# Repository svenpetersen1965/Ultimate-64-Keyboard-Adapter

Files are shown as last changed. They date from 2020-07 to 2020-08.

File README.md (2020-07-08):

# Ultimate-64-Keyboard-Adapter
This is an extension for the Ultimate 64 (elite) keyboard connector to get it into a position, that can be reached easily with the standard length keyboard cable. 

The project includes a 3D printed 16mm stand off, that fits the mounting hole. It fits with this 3D printed <a href="https://www.thingiverse.com/thing:3220123">mounting bracket</a> that can be found on thingiverse.com.

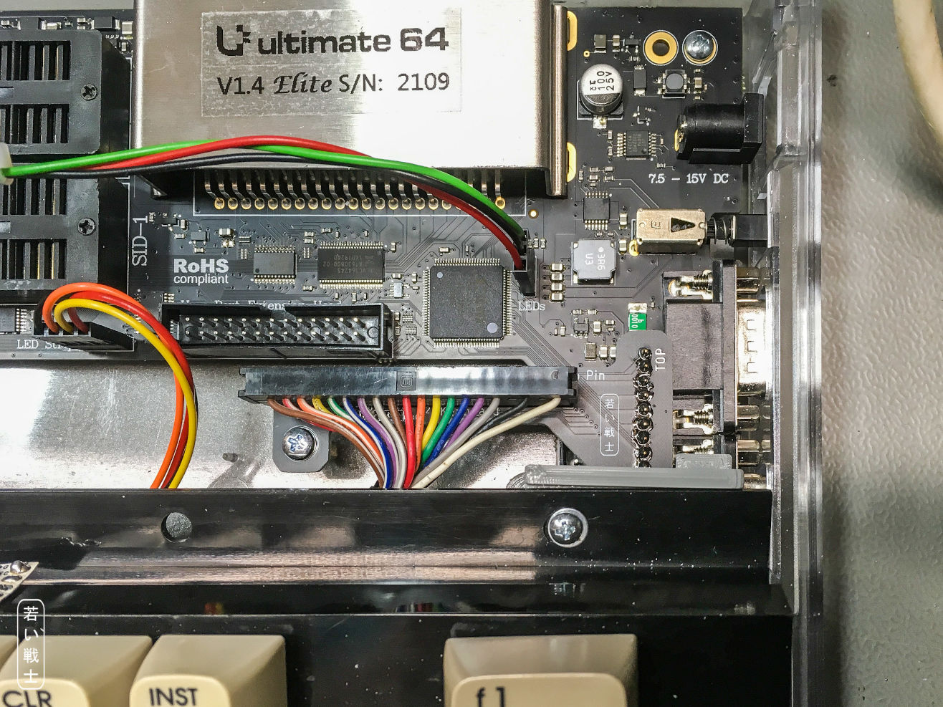
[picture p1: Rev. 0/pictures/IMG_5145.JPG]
U64 KB Adapter mounted


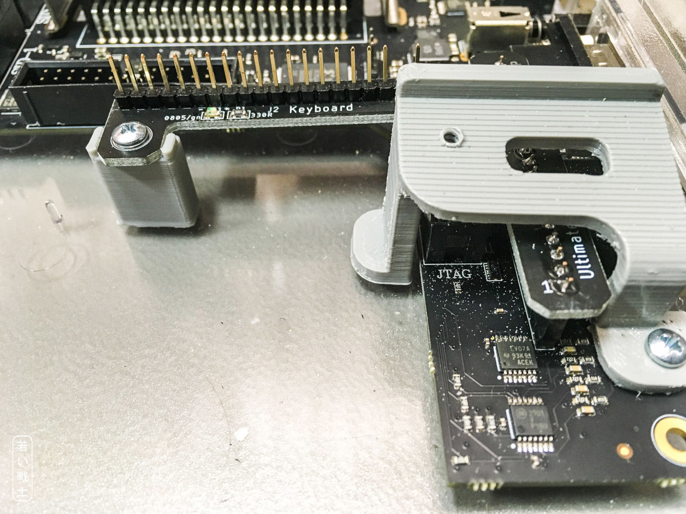
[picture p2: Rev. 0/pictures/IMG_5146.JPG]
U64 KB Adapterwith standoff


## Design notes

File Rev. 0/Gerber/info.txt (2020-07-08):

      
       Board: U64_KB_Ada
       Rev.:  0
  
       Files:
       ======
  
       All Gerber files are generated in extended gerber format (RS274X)
       *.TOP        : Film top copper
       *.BOT        :  -"- bottom copper
       *.STC        :  -"- top soldermask 
       *.STS        :  -"- bottom soldermask
       *.PLC        :  -"- silk screen top
       *.PLS        :  -"- silk screen bottom
       *.CRC        :  -"- cream top
       *.DK         : Drills plated Through (Excellon)
       *.NDK        : Drills not plated Through (Excellon)
       *.OUT        : Board outline

       Board Size:
       ===========
       Length     :   71.0 mm
       Width      :   56.0 mm
       Thickness  :   1.6 mm
       Material   :   FR 4
       Copper     :   35 um
       Surface    :   HASL
       
       Remarks:
       ========
       minimum drill: 0.35mm
       minimum width: 6 mil
       minimum distance: 6 mil

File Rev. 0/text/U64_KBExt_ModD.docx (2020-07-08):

Ultimate 64 Keyboard Extension Rev. 0

Module Description

This is a keyboard extension for the Ultimate 64. It was designed in collaboration with @edu_arana.

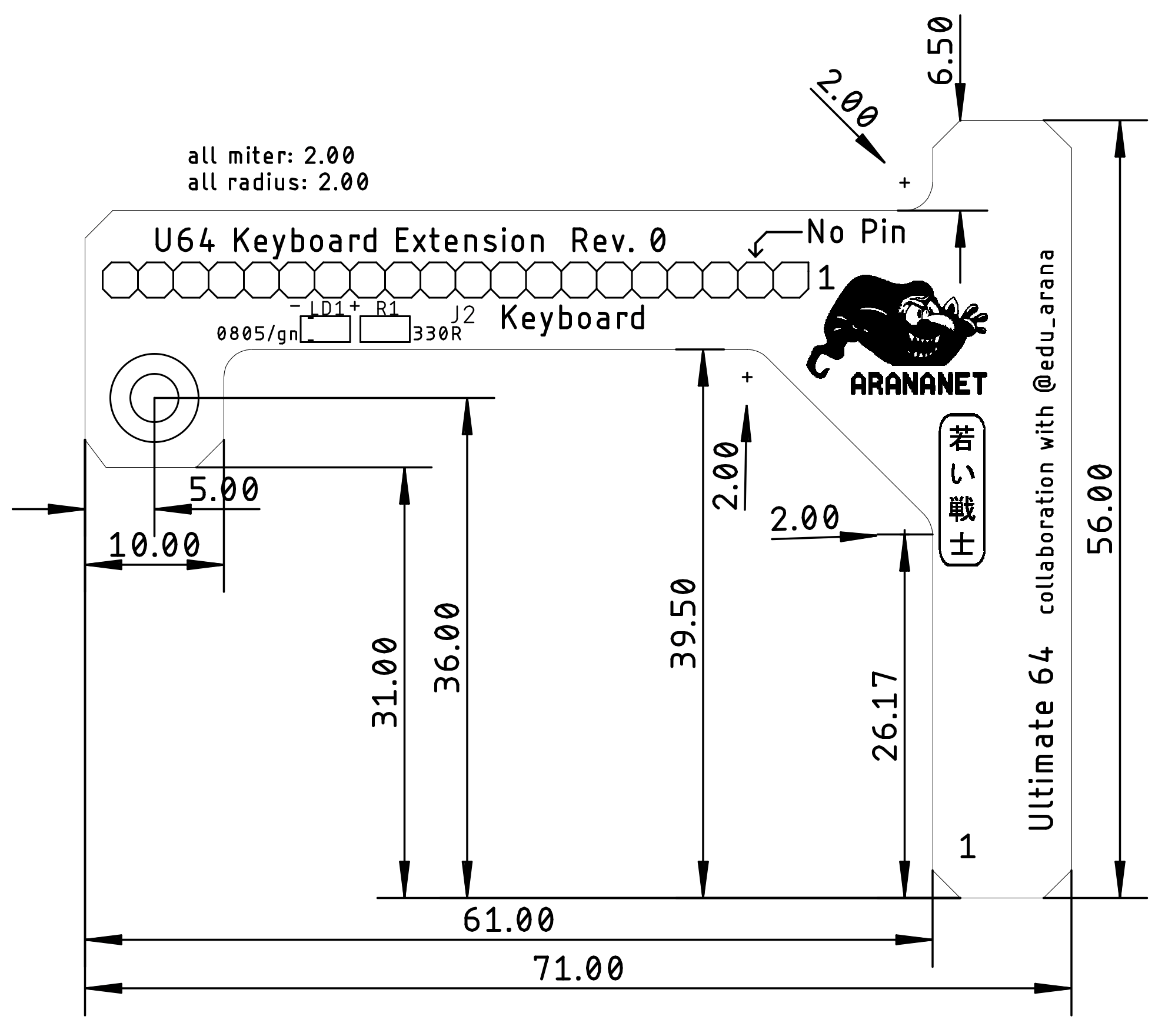
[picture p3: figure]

Figure 1: Dimensions

When using the 3D printed keyboard mounting bracket (https://www.thingiverse.com/thing:3220123), the access to the keyboard connector is blocked. Also, some keyboard cables are too short, so it does not reach the position of the connector or it is installed with a not acceptable tension. The Ultimate 64 Keyboard Extension fixes this problem.

The PCB offers an optional power LED (SMD 0805).

# Connectors

## J1 - Keyboard connector to Ultimate 64

Receptacle (1x20p, pitch 2.54mm) – Harwin M20-7862042

Pin | Signal | Pin | Signal
1 | GND | 11 | ROW1 (PB1)
2 | No pin | 12 | ROW0 (PB0)
3 | | 13 | COL0 (PA0)
4 | +5V | 14 | COL6 (PA6)
5 | ROW3 (PB3) | 15 | COL5 (PA5)
6 | ROW6 (PB6) | 16 | COL4 (PA4)
7 | ROW5 (PB5) | 17 | COL3 (PA3)
8 | ROW4 (PB4) | 18 | COL2 (PA2)
9 | ROW7 (PB7) | 19 | COL1 (PA1)
10 | ROW2 (PB2) | 20 | COL7 (PA7)

## J2 – Pin Header to Keyboard

Standard 1x20p, pitch 2.54. Pin 2 has to be removed to fit the C64 keyboard connector. The pin out is identical to J1.

# Mounting

The distance between this keyboard extension and the bottom of the case depends on the height of the receptacle. With a 8mm high receptacle, it is approximately 16mm. The project includes 3D printed a stand-off of this height.


Figure 2: Mounting of the keyboard extension with stand-off and keyboard bracket

The recommended screw for the stand-off is a C2.9x9.5 DIN 7981.


Figure 3: Complete assembly with keyboard installed

U64_KBExt_ModD.docx 26.06.2020 09:07 Drafted by Sven Petersen Page 2 of 2 Doc.-No.: 151-6-01-00

U64_KBExt_ModD.docx 26.06.2020 09:07 Drafted by Sven Petersen Page 1 of 1 Doc.-No.: 151-6-01-00

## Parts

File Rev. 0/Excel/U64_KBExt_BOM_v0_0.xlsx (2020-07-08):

Ultimate 64 Keyboard Extension Rev. 0
Bill of Material Rev. 0.0
Pos. | Qty | Value | Footprint | Ref.-No. | Comment
1 | 1 | 151-2-01-00 | 2 Layer | PCB Rev. 0 | 2 layer, Cu 35µ, HASL, LLL x BBB, 1.6mm FR4
2 | 1 | 1x20, 2.54mm, h=8mm | 1x20 | J1 | standard receptacle for pin header, pitch 2.54mm, height appr. 8mm
3 | 1 | 1x20p, 2.54mm | 1x20p | J2 | standard pin header 1x20p, pitch 2.54, pin 2 removed
4 | 1 | 330R | 0805 | R1 | optional, SMD 0805 resistor 10% or better
5 | 1 | LED 0805/green | LED0805 | LD1 | optional SMD LED

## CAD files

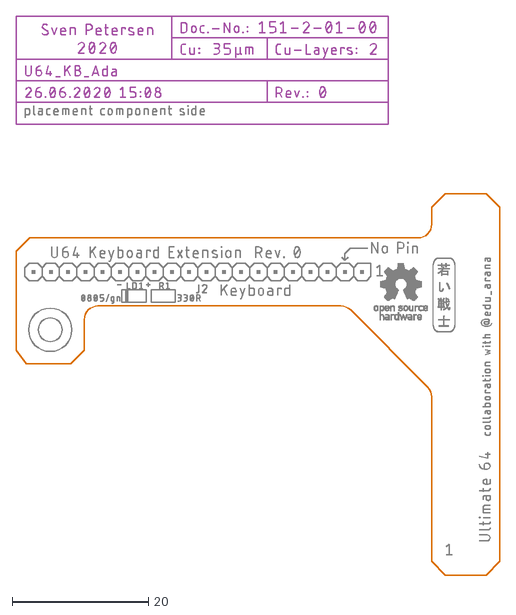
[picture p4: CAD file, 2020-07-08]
Rev. 0/dxf/U64_KB_Ada.dxf
71.0 x 82.1

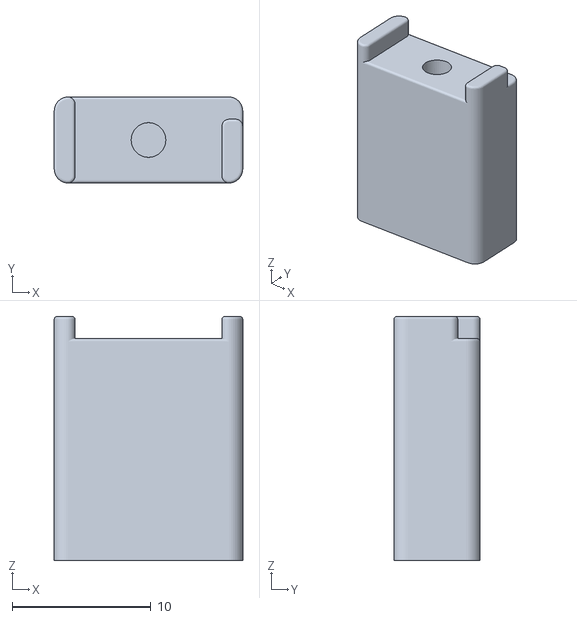
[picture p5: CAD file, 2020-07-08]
Stand_off/STL/U64_KeybExt_StandOff.stl
13.6 x 6.20 x 17.6

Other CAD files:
Stand_off/Fusion360/U64_KeybExt_Support v2.f3d

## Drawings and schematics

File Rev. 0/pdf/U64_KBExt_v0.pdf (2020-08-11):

# Project Documentation

## Ultimate 64 Keyboard Extension

## Project number: 151

## Revision: 0

## Date: 26.06.2020


U64_KBExt_ModD.docx | | 26.06.2020 09:07
Drafted by Sven Petersen | Page 1 of 3 | Doc.-No.: 151-6-01-00

### Ultimate 64 Keyboard Extension Rev. 0

### Module Description

This is a keyboard extension for the Ultimate 64. It was designed in collaboration with @edu_arana.

Figure 1: Dimensions

When using the 3D printed keyboard mounting bracket (https://www.thingiverse.com/thing:3220123), the access to the keyboard connector is blocked. Also, some keyboard cables are too short, so it does not reach the position of the connector or it is installed with a not acceptable tension. The Ultimate 64 Keyboard Extension fixes this problem.

The PCB offers an optional power LED (SMD 0805).

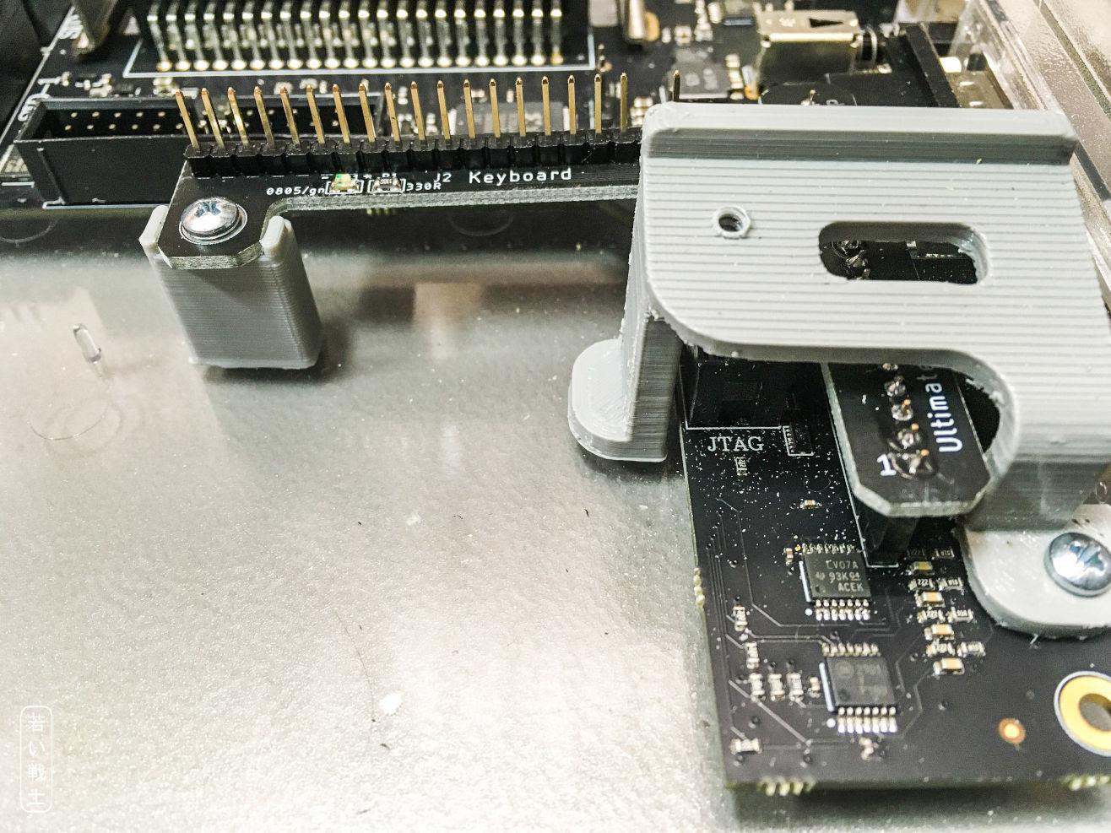
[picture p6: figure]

U64_KBExt_ModD.docx | | 26.06.2020 09:07
Drafted by Sven Petersen | Page 2 of 3 | Doc.-No.: 151-6-01-00

## Connectors

### J1 - Keyboard connector to Ultimate 64

Receptacle (1x20p, pitch 2.54mm) – Harwin M20-7862042

Pin Signal | Pin Signal
1 | GND | 11 | ROW1 (PB1)
2 | No pin | 12 | ROW0 (PB0)
3 RESTORE | | 13 COL0 (PA0)
4 | +5V | 14 | COL6 (PA6)
5 | ROW3 (PB3) | 15 | COL5 (PA5)
6 | ROW6 (PB6) | 16 | COL4 (PA4)
7 | ROW5 (PB5) | 17 | COL3 (PA3)
8 | ROW4 (PB4) | 18 | COL2 (PA2)
9 | ROW7 (PB7) | 19 | COL1 (PA1)
10 | ROW2 (PB2) | 20 | COL7 (PA7)

### J2 – Pin Header to Keyboard

Standard 1x20p, pitch 2.54. Pin 2 has to be removed to fit the C64 keyboard connector. The pin out is identical to J1.

## Mounting

The distance between this keyboard extension and the bottom of the case depends on the height of the receptacle. With a 8mm high receptacle, it is approximately 16mm. The project includes 3D printed a stand-off of this height.

Figure 2: Mounting of the keyboard extension with stand-off and keyboard bracket

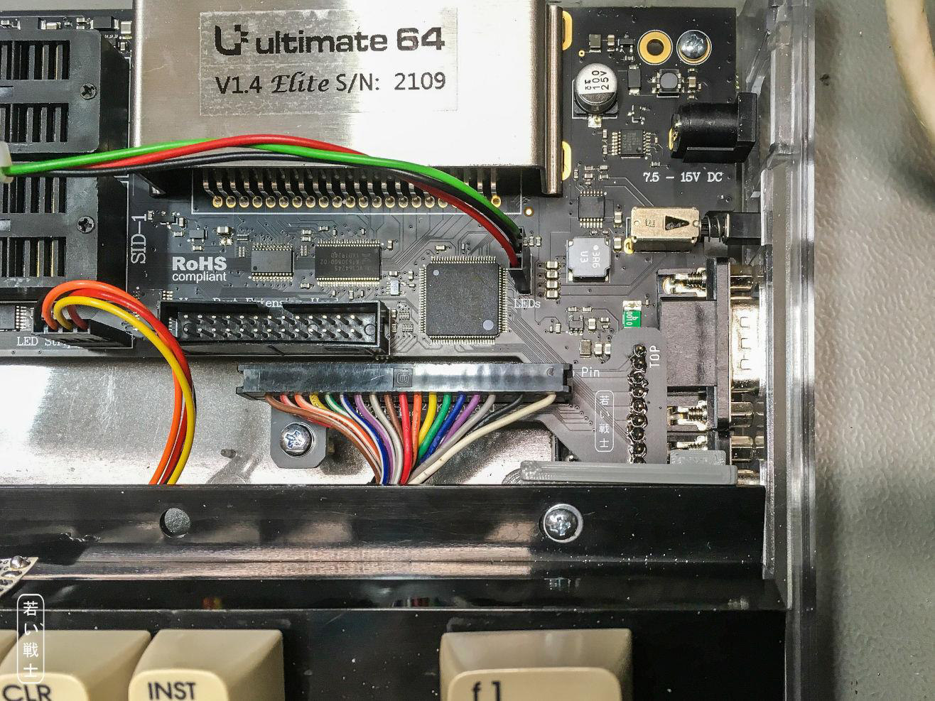
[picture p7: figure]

U64_KBExt_ModD.docx | | 26.06.2020 09:07
Drafted by Sven Petersen | Page 3 of 3 | Doc.-No.: 151-6-01-00

The recommended screw for the stand-off is a C2.9x9.5 DIN 7981.

Figure 3: Complete assembly with keyboard installed

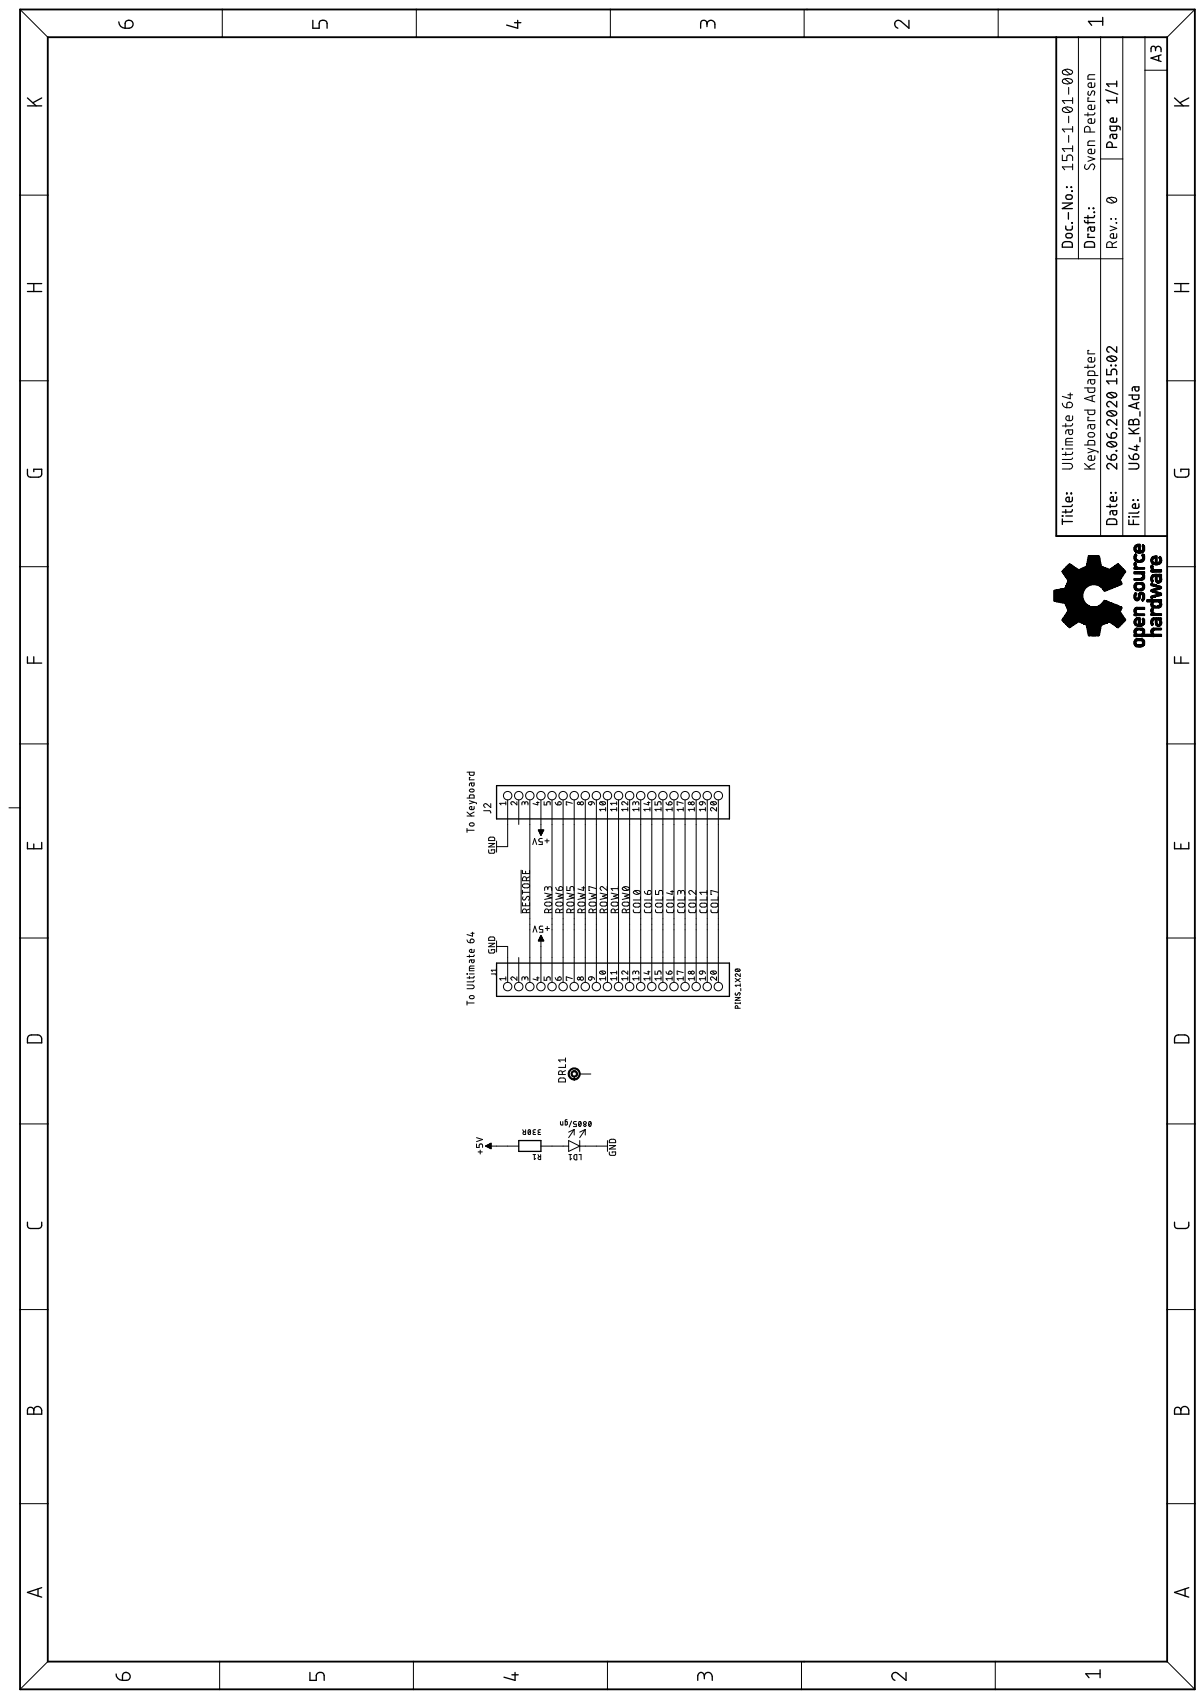
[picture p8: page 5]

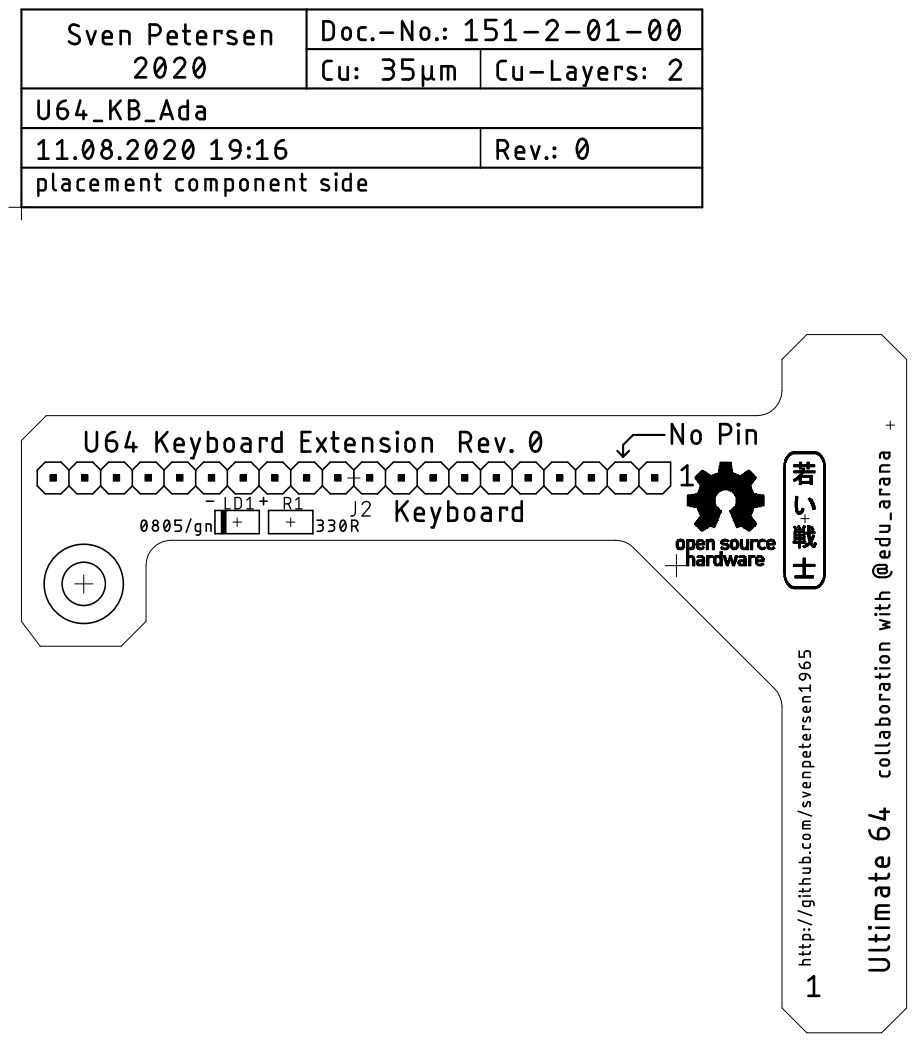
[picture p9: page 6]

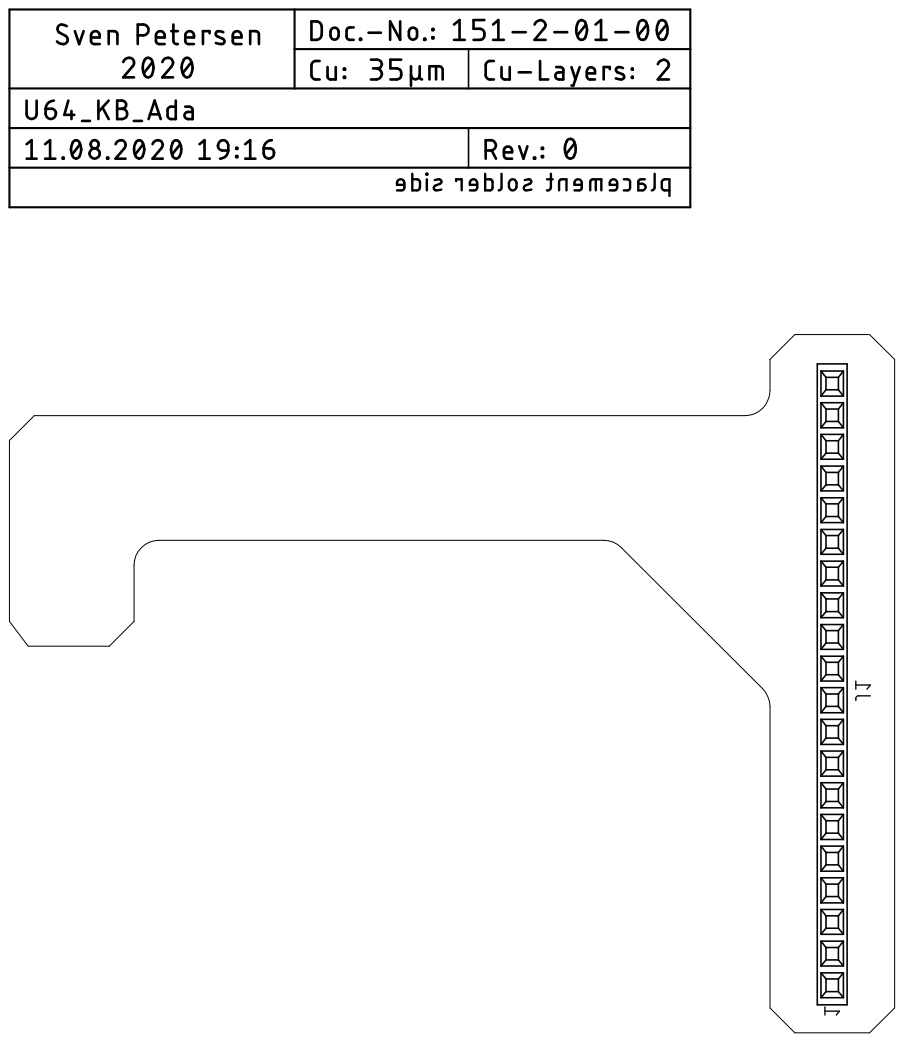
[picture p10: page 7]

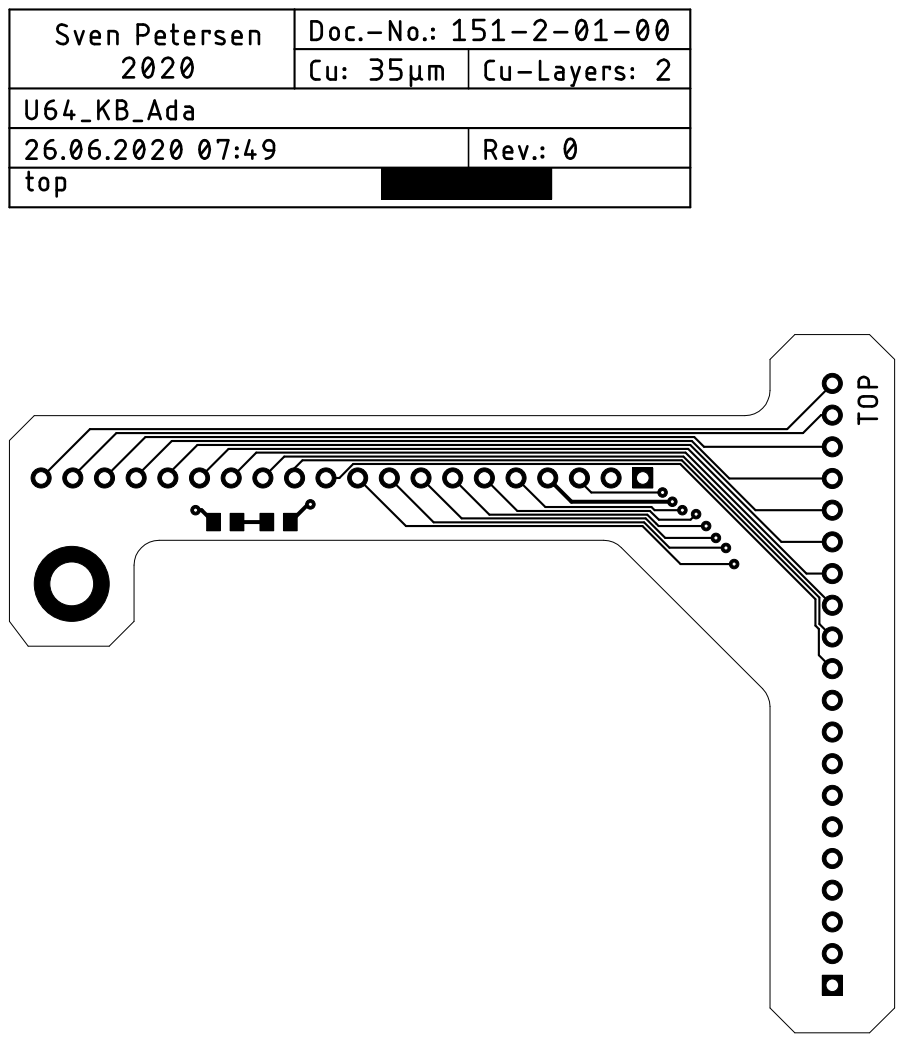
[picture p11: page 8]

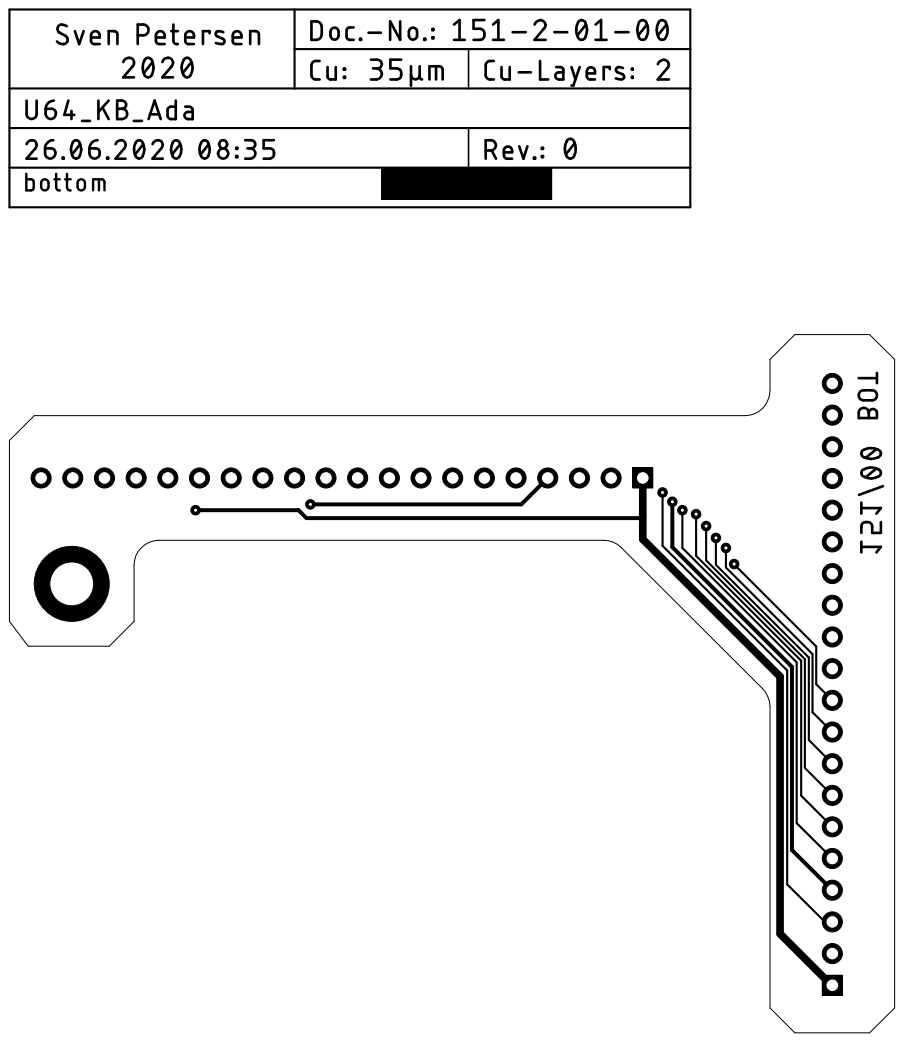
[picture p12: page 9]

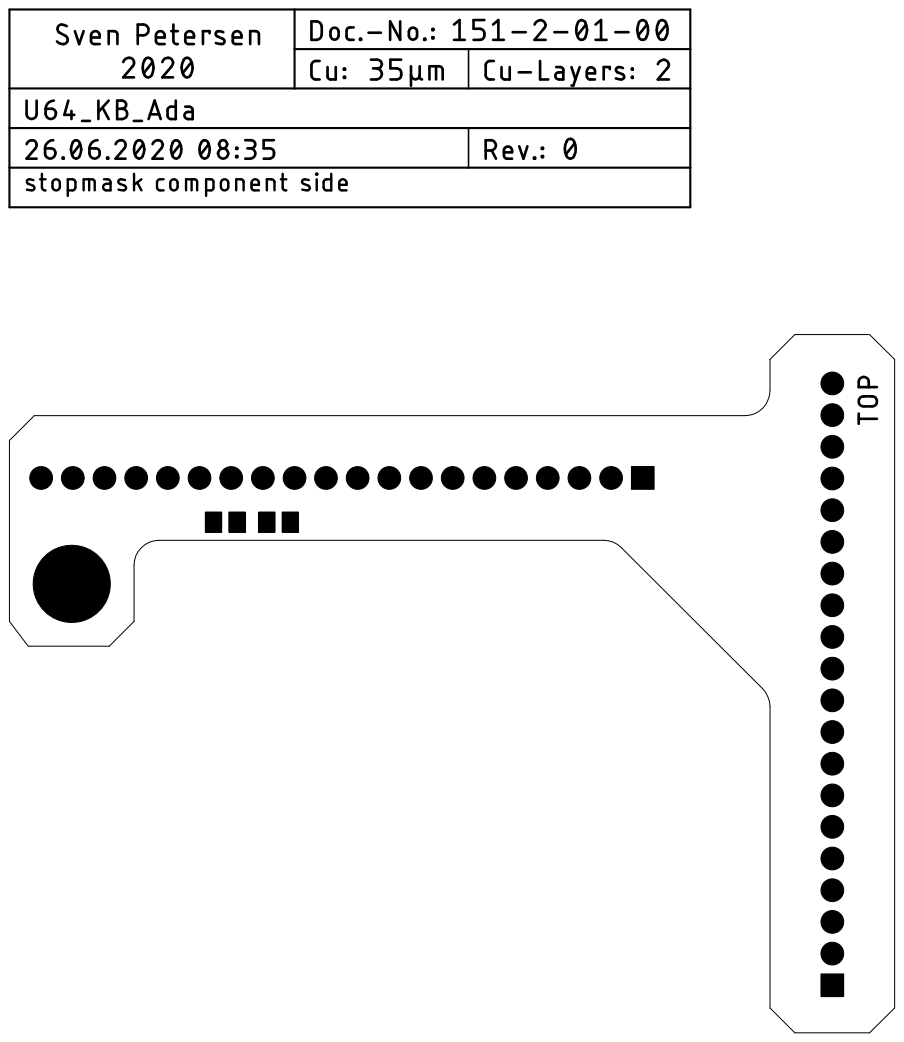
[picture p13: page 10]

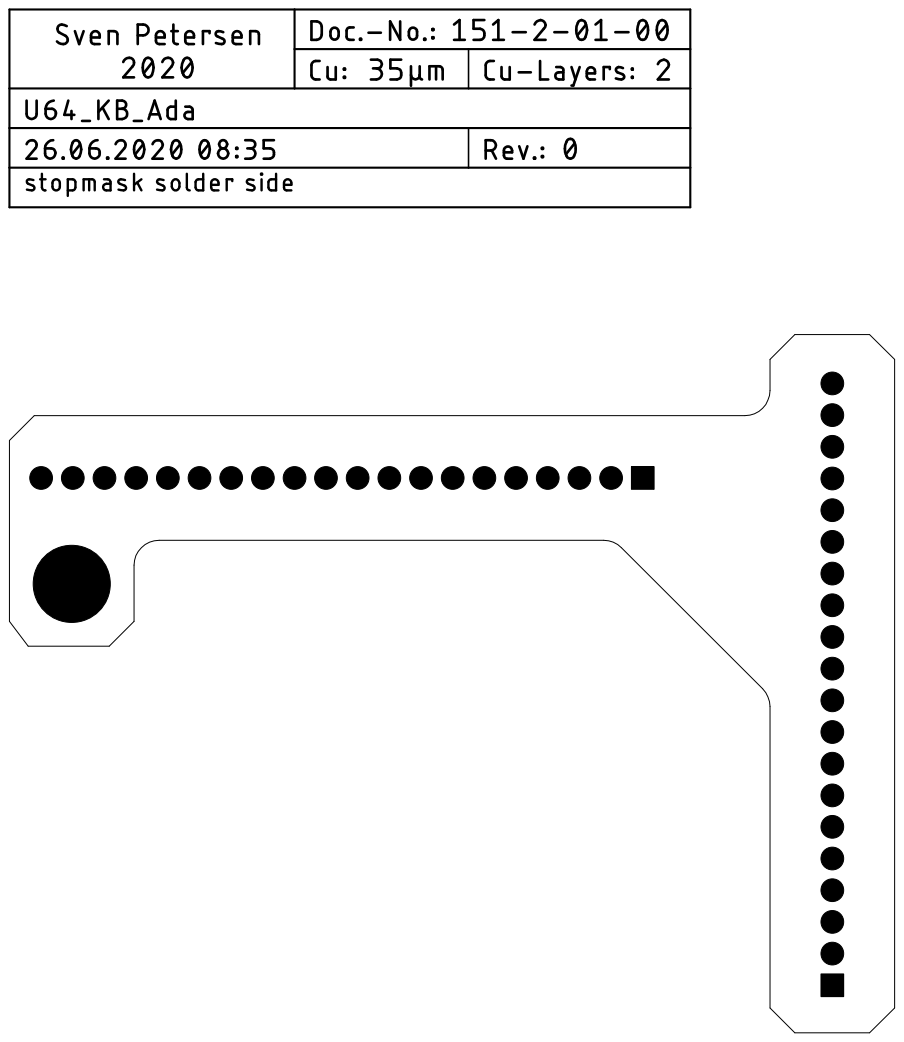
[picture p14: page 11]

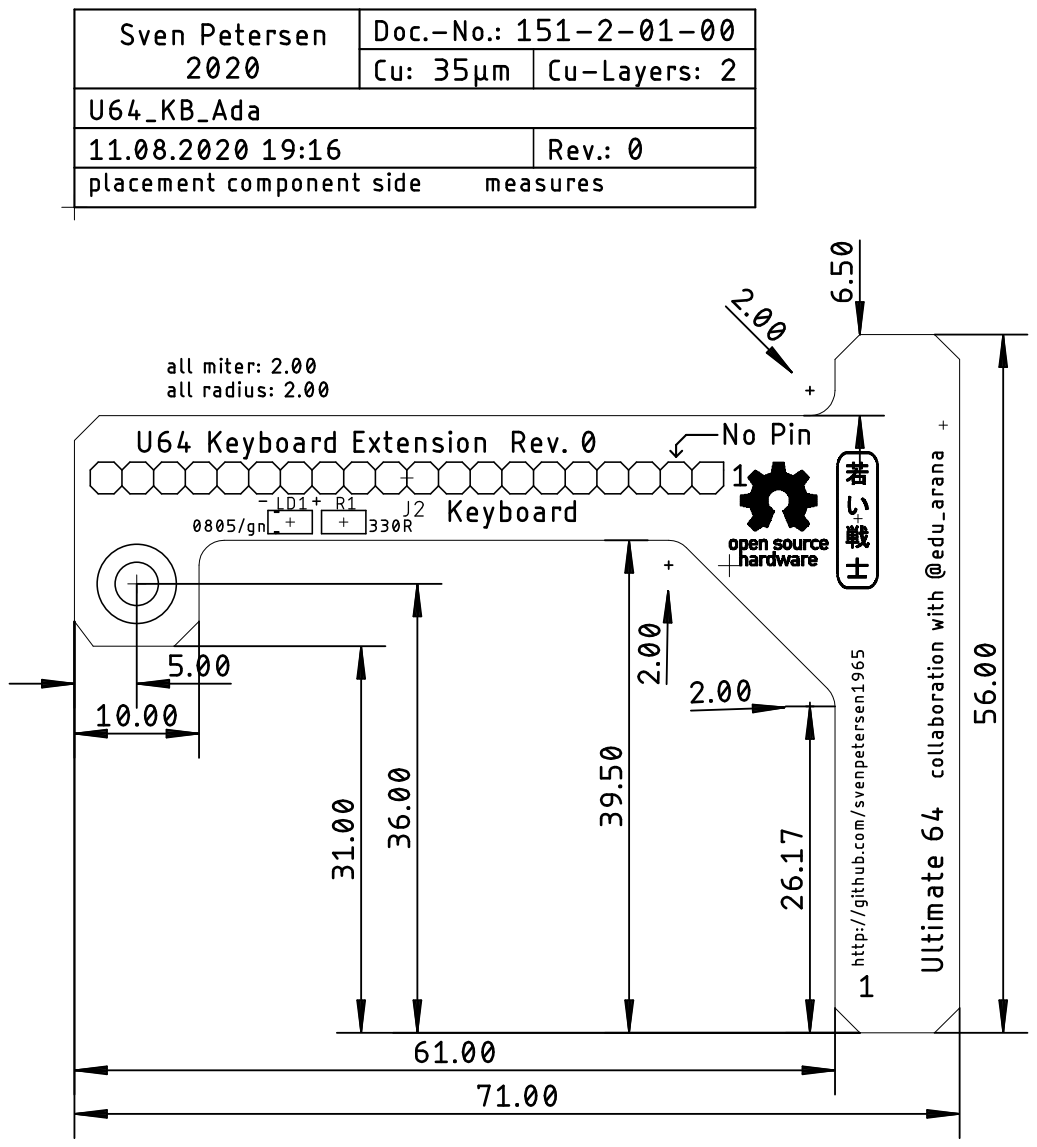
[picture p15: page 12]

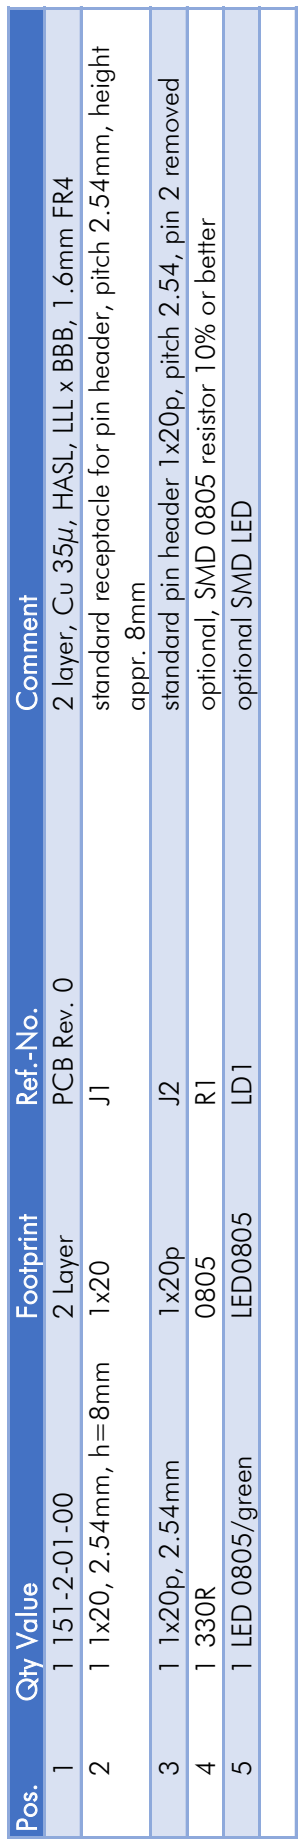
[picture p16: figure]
appr. 8mm

Pos. Qty Value Footprint Ref.-No. Comment

1 1 151-2-01-00 2 Layer PCB Rev. 0 2 layer, Cu 35µ, HASL, LLL x BBB, 1.6mm FR4

2 1 1x20, 2.54mm, h=8mm 1x20 J1 standard receptacle for pin header, pitch 2.54mm, height
3 1 1x20p, 2.54mm 1x20p J2 standard pin header 1x20p, pitch 2.54, pin 2 removed

4 1 330R 0805 R1 optional, SMD 0805 resistor 10% or better

5 1 LED 0805/green LED0805 LD1 optional SMD LED

## Ultimate 64 Keyboard Extension Rev. 0

## Bill of Material Rev. 0.0

U64_KBExt_BOM_v0_0.xlsx

Drafted by Sven Petersen Page 1 of 1

26.06.2020 09:19
Doc.No.: 151-5-01-00.0

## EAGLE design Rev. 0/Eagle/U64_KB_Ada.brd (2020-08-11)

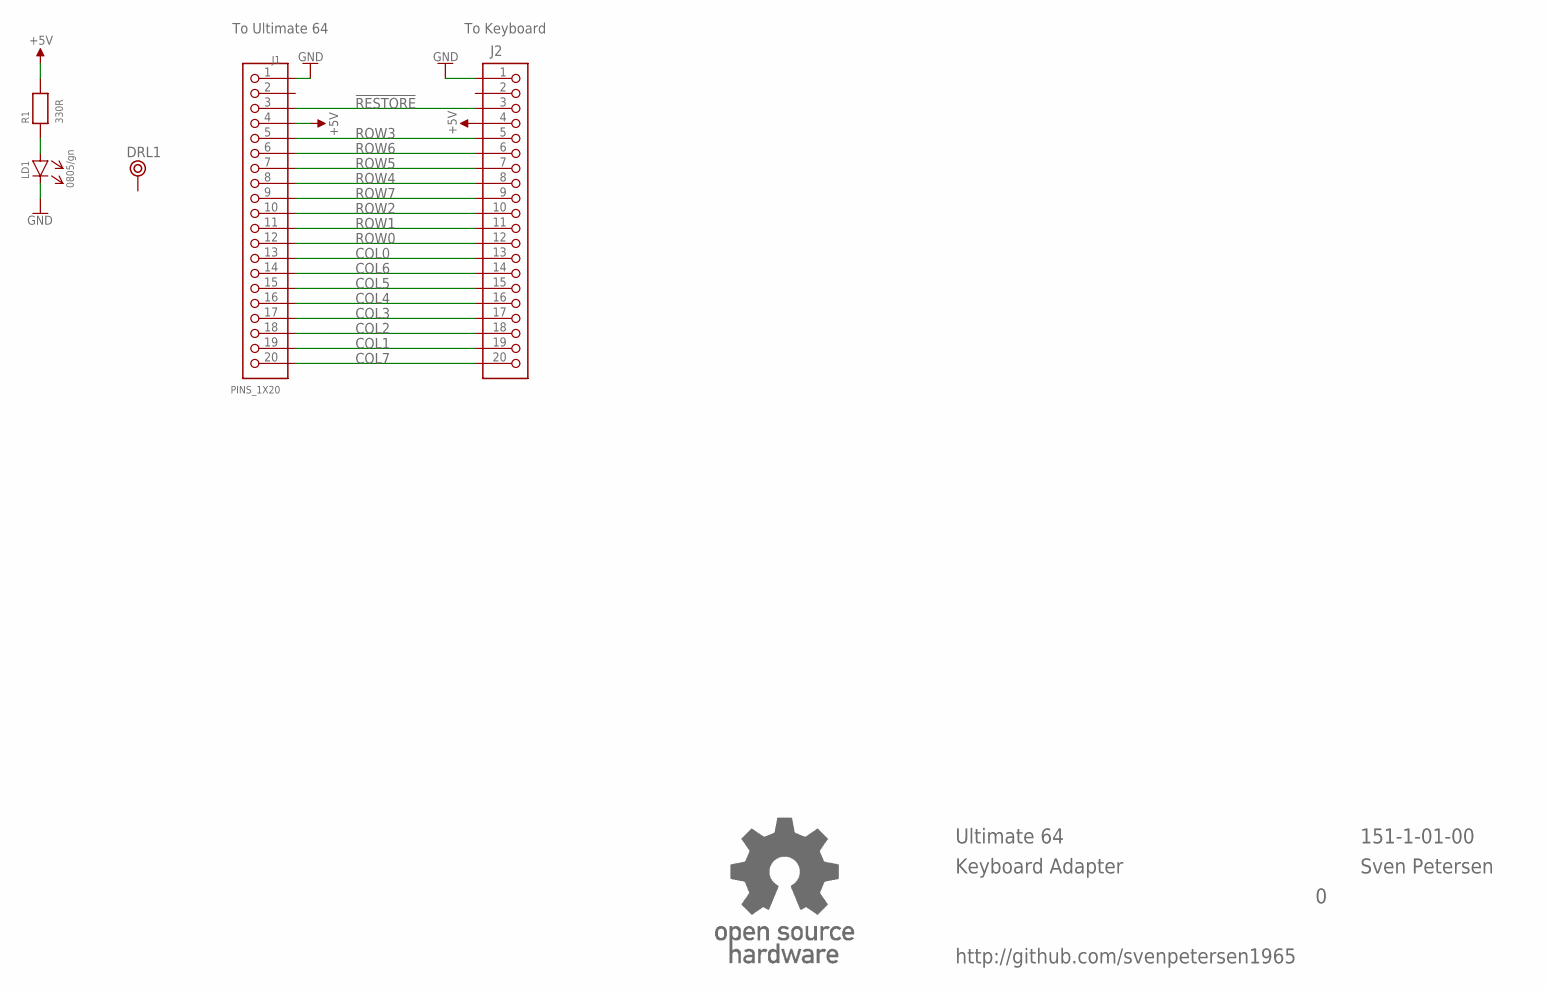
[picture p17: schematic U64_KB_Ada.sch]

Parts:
DRL1: BOHR3,5
J1: PINS_1X20; PINS_1X20V
J2: PINHD-1X20; 1X20
LD1: 0805/gn; 0805
R1: 330R; 0805
U$12: OPEN_SOURCE_HW; OPENHW

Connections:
!RESTORE: J1.3, J2.3
+5V: J1.4, J2.4, R1.2
COL0: J1.13, J2.13
COL1: J1.19, J2.19
COL2: J1.18, J2.18
COL3: J1.17, J2.17
COL4: J1.16, J2.16
COL5: J1.15, J2.15
COL6: J1.14, J2.14
COL7: J1.20, J2.20
GND: J1.1, J2.1, LD1.K
unnamed: LD1.A, R1.1
ROW0: J1.12, J2.12
ROW1: J1.11, J2.11
ROW2: J1.10, J2.10
ROW3: J1.5, J2.5
ROW4: J1.8, J2.8
ROW5: J1.7, J2.7
ROW6: J1.6, J2.6
ROW7: J1.9, J2.9

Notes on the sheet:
To Keyboard
To Ultimate 64
Ultimate 64
Keyboard Adapter
151-1-01-00
Sven Petersen
http://github.com/svenpetersen1965

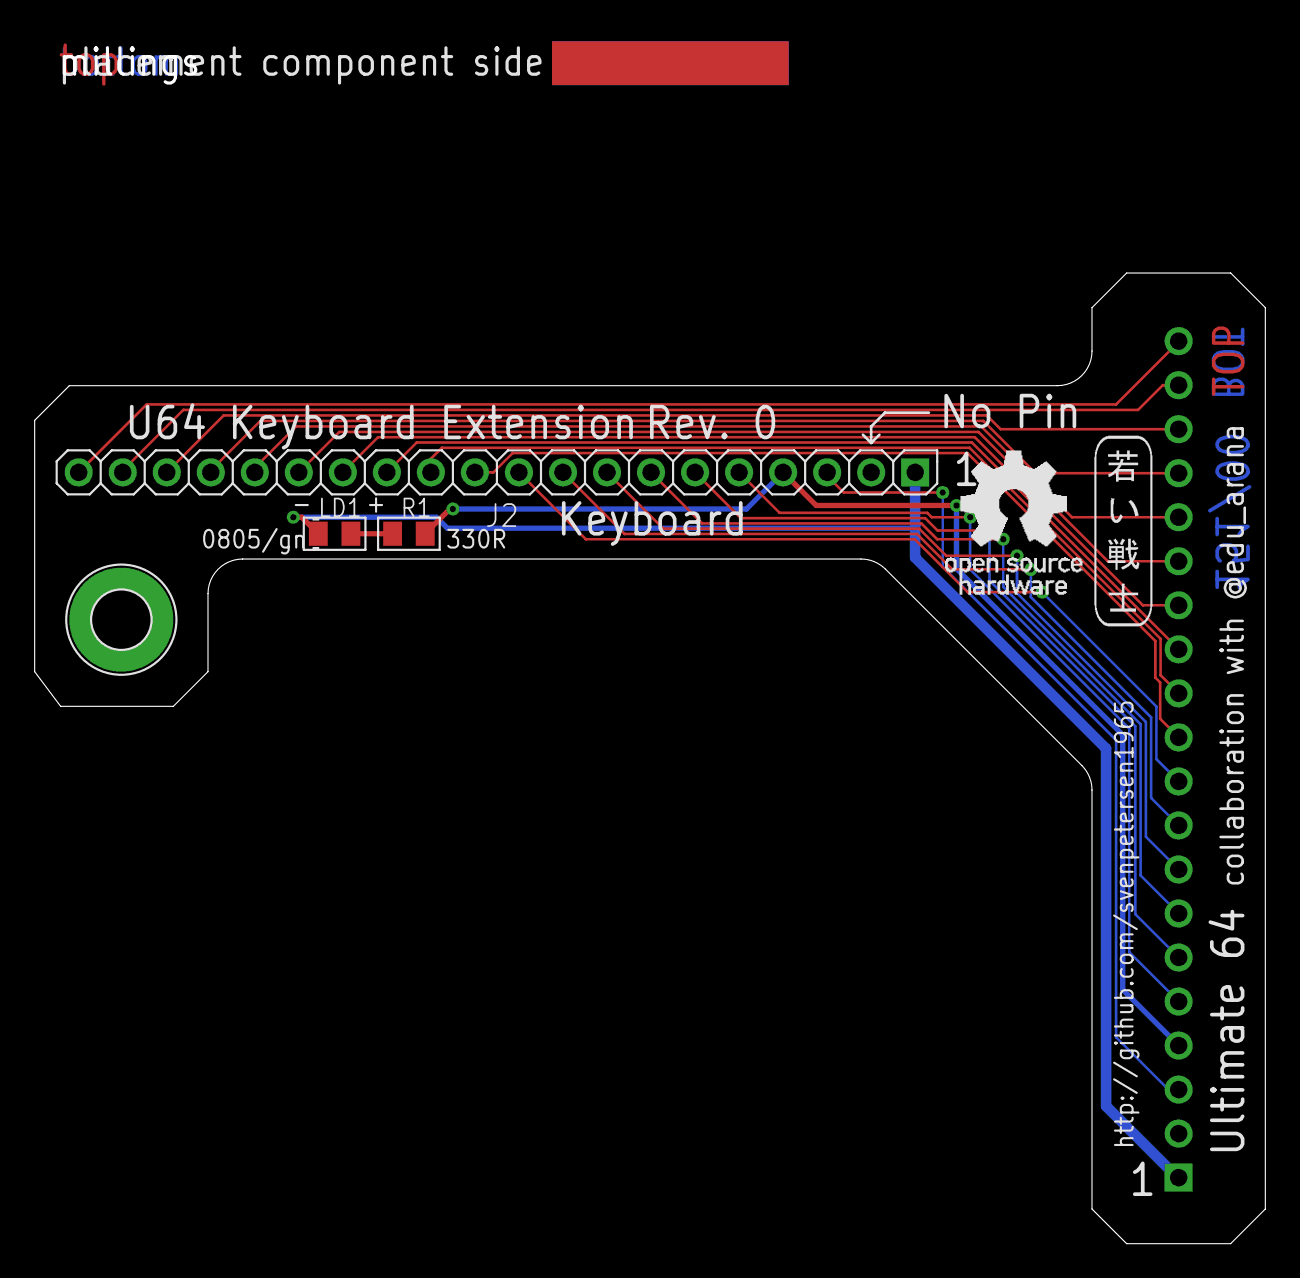
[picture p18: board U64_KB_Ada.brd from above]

Board: 2 copper layers, 71.0 x 56.0 mm, 9 parts (1 on the bottom side), 20 nets.

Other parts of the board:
U$6: 2LAYER
U$9: SVEN_TAG
U$10: PCB-TITLE/
